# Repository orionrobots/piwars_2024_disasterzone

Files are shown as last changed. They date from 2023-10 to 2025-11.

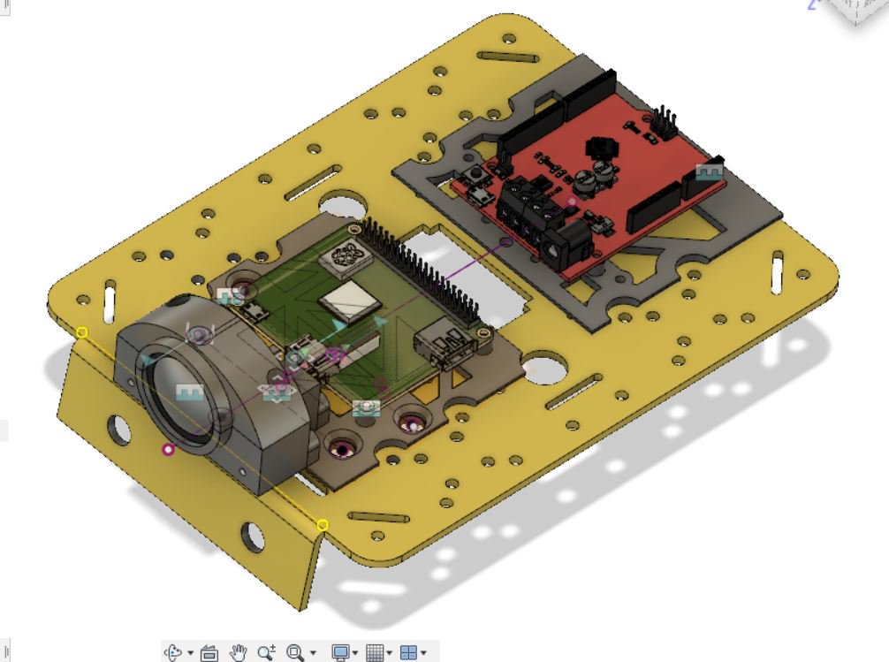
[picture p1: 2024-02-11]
hardware/pictures_for_blog/Dx8H_vfXQAc5lHb.jpg

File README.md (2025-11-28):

# piwars_2024_disasterzone

Code for Piwars 2024 robot

## 📋 Validation Infrastructure

See **[VALIDATION_ROADMAP.md](VALIDATION_ROADMAP.md)** for the plan to add offline validation (CI, testing, simulation).

## road map for motor board

Let's make the interface the same as the [GPIOzero Robot](https://gpiozero.readthedocs.io/en/stable/api_boards.html#robot). We can support this for multiple motor boards, and it will make it easier to swap them out.

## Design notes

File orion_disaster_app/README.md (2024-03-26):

# Orion disaster robot control app

This is an app designed to interact with the robot from a device.

It uses expo/react native.

## Installation

- Ensure you have up-to-date node.
- Install with `npm install`.
- Run with `npm run go`.
- Install the expo go app on your android/ios device.
- Scan the QR code with the camera, which shoudl launch the app.

You will need to close the app and re-open it with the QR code when you stop/start the
server.

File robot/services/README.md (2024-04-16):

# Services

These are robot mqtt services.

Each should have the following:

- notes.md -> Notes on the device/board/algorithm.
- service.py -> Main service code.
- install.py -> PyInfra code to install the service and dependencies.
    - Should include installing a systemd unit file, and restarting if necessary.
- service.j2 -> template for the service systemd file.

## Sending a message to a service

To send a message to a service, publish to the topic:

```bash
source /etc/robot.env
mosquitto_pub -t "motors/forward" -m '{"speed": 1}' -u $MQTT_USERNAME -P $MQTT_PASSWORD
```

Robot.env is deployed from your .env, and will contain the needed secrets for mqtt access.

## Tips

Vacuum logs - `journalctl --vacuum-time=2d` - keep only 2 days. These MQTT services can generate a lot of logs!

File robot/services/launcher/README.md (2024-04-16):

# Launcher service

An MQTT service to launch/stop other services.
Can also power down the Raspberry Pi.

## Messages and topics

- launcher/start 'service_name' : Start the service 'service_name'
- launcher/stop 'service_name' : Stop the service 'service_name'
- launcher/poweroff : Power off the Raspberry Pi

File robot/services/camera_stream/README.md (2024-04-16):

# Camera commands we can use (pre-python)

- https://www.tomshardware.com/how-to/use-raspberry-pi-camera-with-bullseye
- https://www.raspberrypi.com/documentation/computers/camera_software.html - This is bookworm, so newer than the bullseye installed here.

## Getting a still

```bash
libcamera-still --datetime -e png --rotation 180
ls *.png
```

Retrieve it:

`
rsync danny@big-ole-yellow.local:0415195843.png .
`

You can now view locally

## Streaming

```bash
libcamera-vid --rotation 180 --listen -o

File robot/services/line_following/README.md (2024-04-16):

## Line Following Control
- line_following/startstop - empty payload to start/stop the line following service.
- all/stop - empty payload to stop all services.
- listening to line_follower/differences for line sensor readings.

## Line Following Output
- line_follower/control
- motors/left, motors/right

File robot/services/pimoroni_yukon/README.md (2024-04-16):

# Pimoroni Yukon robot service

Slot usage plans:
- Slots 2 and 4 are motors + encoders
- 4 is an LED Strip
- 5 Servo motors

| Other services | --> | MQTT Broker (Mosquitto) | --> | Yukon Service (Runing on the Pi) | --> Serial port ==> | Yukon |

## Links and docs

- https://github.com/pimoroni/yukon/blob/main/docs/reference.md#pimoroni_yukon-reference
- https://pythonhosted.org/pyserial/examples.html#tcp-ip-serial-bridge
- https://forum.micropython.org/viewtopic.php?t=11336
- https://shop.pimoroni.com/products/yukon?variant=41185258111059
- https://shop.pimoroni.com/products/big-motor-encoder-module-for-yukon?variant=41186939437139
- https://pypi.org/project/mpremote/

## Communication

Currently, the firmware on the Yukon is Micropython based. Over USB that only offers a single REPL/Serial.
We will do the follwoing:
- Use MPRemote to start/stop/deploy code.
- When it is running, use the repl to send commands to this part of the robot.

The communication protocol can be nice and simple. Since we are working with MQTT, we can translate to serial:
- The service subscribes to topics.
- Any topic it's subscribed to is passed on to the robot - topic/name:payload
- An end of payload is denoted by what? Its a line for now. topic/name:payload\n.
- Any serial responses are published to the topic: topic/name:payload

The commands for the motor will be the same as other motor services here.

## Mounting and reflashing the firmware on the RP2040 on Yukon

From time to time, a micropython firmware update may be needed. This is how you do it:

- Download the latest firmware for Yukon.
- Stop the yukon service with: `sudo systemctl stop yukon`
- Power off the yukon.
- Hold the boot/user button and power it on.
- `sudo mkdir -p /mnt/pico`
- `sudo mount  sudo mount /dev/sda1 /mnt/pico`
- `sudo cp <firmware> /mnt/pico`
- `sudo sync`
- `sudo umount /mnt/pico`
- You should probably run the installer here again.

Refer to section 3.2.1 in https://datasheets.raspberrypi.com/pico/getting-started-with-pico.pdf.

## Updating the Pimoroni yukon libraries

- Stop the yukon service with: `sudo systemctl stop yukon`
- Download the libaries, unzip them.
- cd into the directory.
- mpremote cp lib :
- You probably want to run the install/restart the service now

## Sunfounder Line Follower Module

- https://github.com/sunfounder/SunFounder_Line_Follower
```python
>>> from machine import Pin, I2C
>>> i2c = I2C(0)
>>> i2c.scan()
[17, 32, 38]
>>> [int (n) for n in i2c.readfrom(0x11, 10)]
[0, 12, 0, 33, 0, 17, 0, 16, 0, 9]
>>> [int (n) for n in i2c.readfrom(0x11, 10)]
[0, 182, 0, 169, 0, 162, 0, 219, 0, 175]
>>> i2c.readfrom(0x11, 10)
b'\x00\x0e\x00!\x00\x11\x00\x12\x00\t'
>>> struct.unpack(">HHHHH",  i2c.readfrom(0x11, 10))
(13, 13, 15, 16, 7)
>>> struct.unpack(">HHHHH",  i2c.readfrom(0x11, 10))
(11, 123, 389, 406, 327)
```
Device address is 0x11. 0x32 and 0x38 are IO extenders on the Yukon.

## Line Following Module MQTT Protocol
- Control messages topics are 'line_follower/control {"enabled": true}' and 'line_follower/control {"enabled": false}'.
- The line sensor readings are published to 'line_follower/differences' as a JSON object: [0, 0, 0, 0]

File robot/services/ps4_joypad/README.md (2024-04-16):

# Playstation 4 JoyPad service

This service allows you to control the robot using a PS4 controller. The intention is to patch the Joystick to emit events to the MQTT bus to control other services.

## Decision

One decision is if the Joypad would emit generic events, like joystick moved, and button press events, or to make it a direct control surface, like the phone app, and emit motors move and similar events directly.

For now, this service will emit direct motor and servo control events.

## Installation

This is a pyinfra based installation. The installation will need the following:

- A PS4 controller.
- You will need to pair and trust this with the Pi. This is a one time operation.
    - Using the command Bluetoothctl from ssh:
```bluetoothctl
discoverable on
pairable on
agent on
default-agent
scan on
```
Wait for the controller to appear, then:
```bluetoothctl
pair <controller mac>
trust <controller mac>
```
- Note the MAC for future use, this will become part of the environment for the Pi.
- The installer will install required packages and the service.

## Service intention

- The service will be started at boot, but will not try to connect the joypad, or issue commands until a Yukon/button a press occurs. At this point, it will do a bluetoothctl connect command, wait a short time, and seek the controller device.
- It will then havea  main loop issuing commands on stick events.

## Mappings

The mappings are as follows:
- Left analog stick: control the wheels/tracks
- Right analog stick: control servo 0,1 - pan and tilt on the nerf turret
- Left trigger held: Arm the rollers. When it's released, the rollers will stop.
- Right trigger: Fire the nerf dart
- Triangle: Stop all motors

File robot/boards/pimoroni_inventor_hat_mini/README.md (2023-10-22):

# Notes on Pimoroni inventor hat mini

Code:
- https://github.com/pimoroni/inventorhatmini-python/blob/main/inventorhatmini/__init__.py
- https://github.com/pimoroni/inventorhatmini-python/tree/main

This hat can do more - it has on board lights and audio output.

- https://shop.pimoroni.com/products/inventor-hat-mini?variant=40588023464019
- https://pinout.xyz/pinout/inventor_hat_mini

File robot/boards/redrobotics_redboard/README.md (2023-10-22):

# Notes on RedRobotics Redboard+

This is for driving a robot using the [RedRobotics Redboard+](https://github.com/RedRobotics/RedBoard). This board deals with nearly everything a Raspberry Pi robot will need.

Like the other motor modules in this project, it will follow the GPIOZero robot interface.  

## Setup

The repo describes setup as `curl -L https://raw.githubusercontent.com/RedRobotics/RedBoard/master/system/setup.sh | bash`.

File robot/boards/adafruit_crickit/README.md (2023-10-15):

# Notes on Adafruit Crickit

https://learn.adafruit.com/adafruit-crickit-hat-for-raspberry-pi-linux-computers
Download seesaw firmware:
https://github.com/adafruit/seesaw/releases/tag/1.1.6

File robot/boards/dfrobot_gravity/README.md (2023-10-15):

# Notes on Gravity Expansion Hat

This is for driving a robot using the [DFRobot Gravity Expansion hat](https://thepihut.com/products/gravity-io-expansion-hat-for-raspberry-pi-4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), plus an external motor driver board connected to it's pins.

Like the other motor modules in this project, it will follow the GPIOZero robot interface.  

- [Product wiki](https://wiki.dfrobot.com/IO%20Expansion%20HAT%20for%20Raspberry%20Pi%20%20SKU%3A%20%20DFR0566)
- [Expansion hat](https://thepihut.com/products/gravity-io-expansion-hat-for-raspberry-pi-4)
- [Motor driver](https://thepihut.com/products/gravity-2x-1-2a-dc-motor-driver-tb6612fng) - This is just a TB6612fng with headers

## Setup

The wiring is as follows, using the gravity modular wires:

| Motor Driver | Gravity Hat | Raspberry Pi |
| --- | --- | --- |
| PWM1 | PWM0 | I2C |
| DIR1 | D0 | GPIO 0 |
| PWM2 | PWM1 | I2C |
| DIR2 | D1 | GPIO 1 |

This allows the motor board to use only 2 PWM outputs, freeing up a further 2 for use with servo motors.

## Usage

We should be able to see the board on I2C when we power up the Pi.

For example: `fab -e -H danny@learnrob3.local show-i2c-devices`

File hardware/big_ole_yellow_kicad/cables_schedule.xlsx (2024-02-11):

Cables for robot |  | Type | Length
Pi I2c | Arduino I2c | 3 pin XH
3xXH | 3xXH
GND | GND
SCL | SCL
SDA | SDA
Pi I2C | Line Sensor | 4 pin XH
5V | scl
SDA | sda
SCL | 5v
GND | GND
Pi | HC SR04 | 4 pin XH to 4 Pin dupont
3v | 3v | 3x
sig | sig
sig | sig
gnd | gnd
Arduino | WS2801 | 4 pin XH
5v | 5v
sig | sig
sig | sig
gnd | gnd

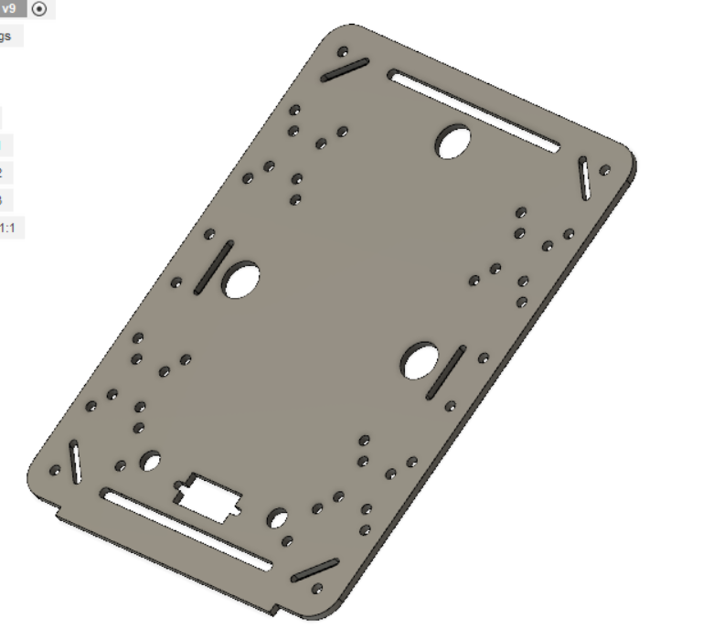
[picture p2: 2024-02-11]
hardware/pictures_for_blog/chassis_plate.PNG

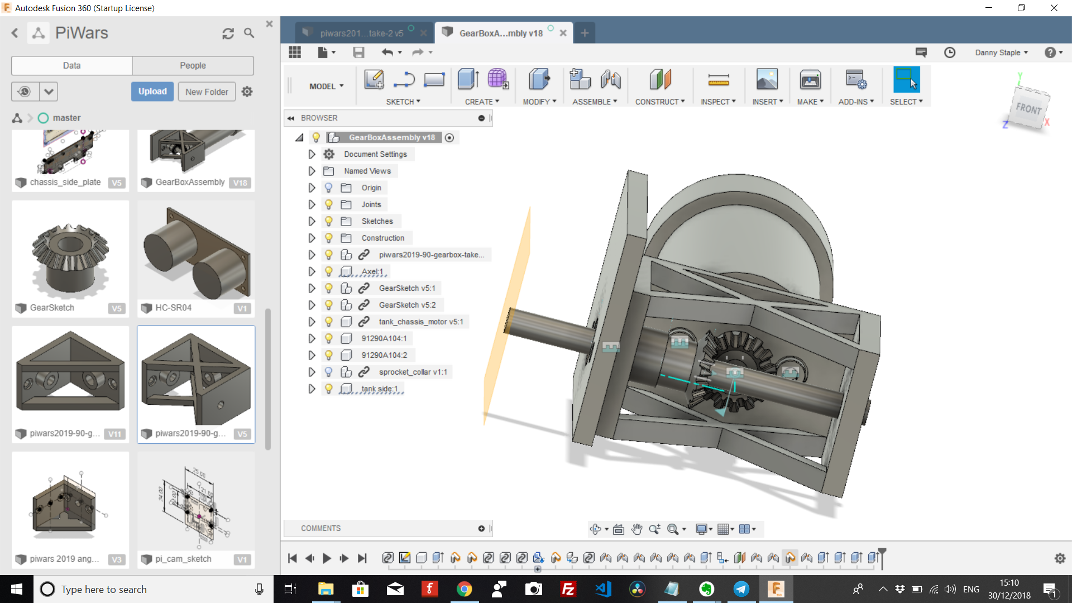
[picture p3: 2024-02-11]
hardware/pictures_for_blog/Screenshot 2018-12-30 15.10.52.png

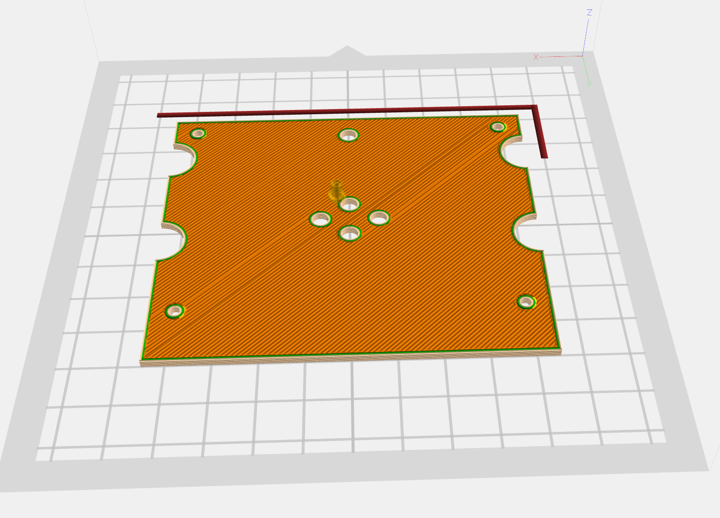
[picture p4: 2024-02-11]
hardware/pictures_for_blog/Screenshot 2023-12-10 at 17.55.50.png

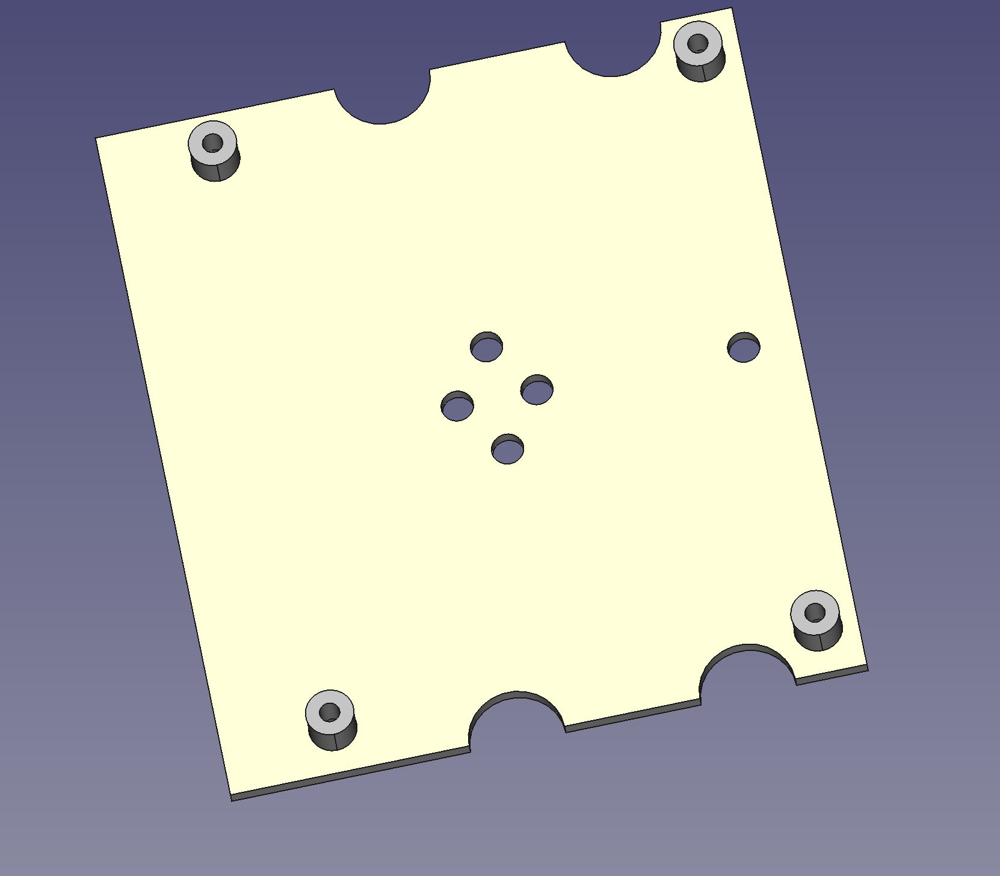
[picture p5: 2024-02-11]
hardware/pictures_for_blog/Screenshot 2023-12-10 at 17.55.58.png

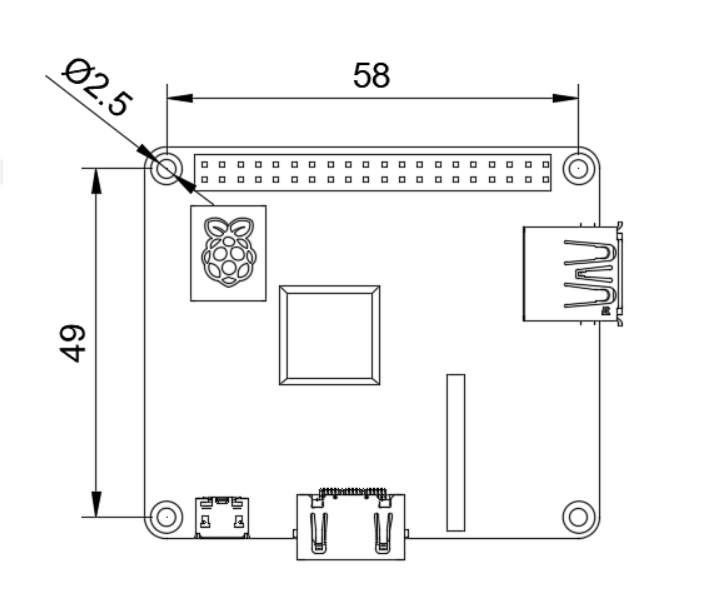
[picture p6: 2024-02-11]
hardware/pictures_for_blog/pi_drawing.png

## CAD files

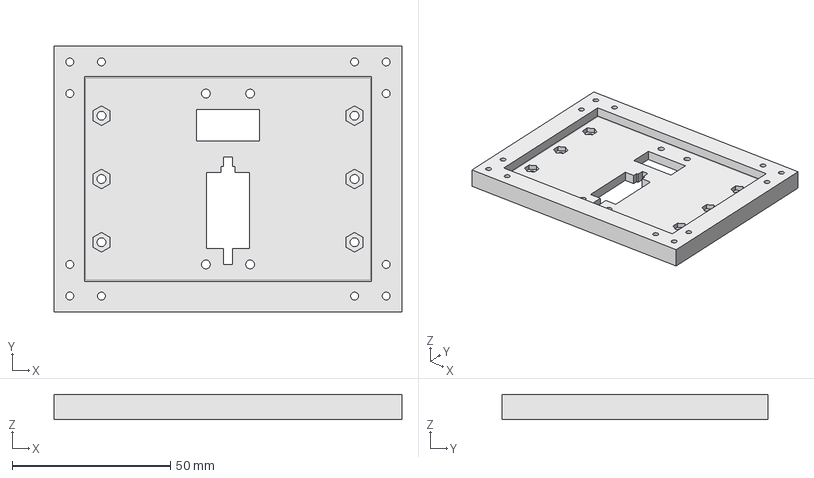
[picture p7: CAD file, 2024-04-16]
hardware/freecad_designs/attachment_mounting_plate.FCStd
110.0 x 84.0 x 8.00 mm

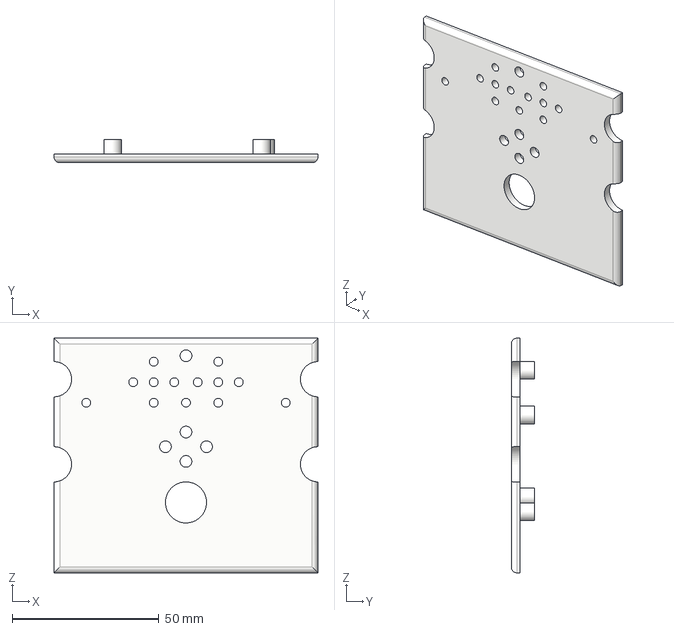
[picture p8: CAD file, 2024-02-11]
hardware/freecad_designs/imported/4DuinoPlate.step
90.0 x 8.00 x 80.0 mm

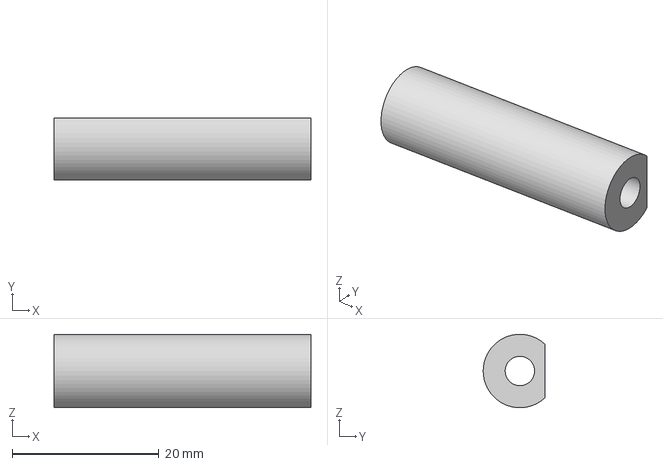
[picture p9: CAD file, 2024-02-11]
hardware/freecad_designs/imported/sprocket_collar v1.step
35.0 x 8.40 x 10.00 mm

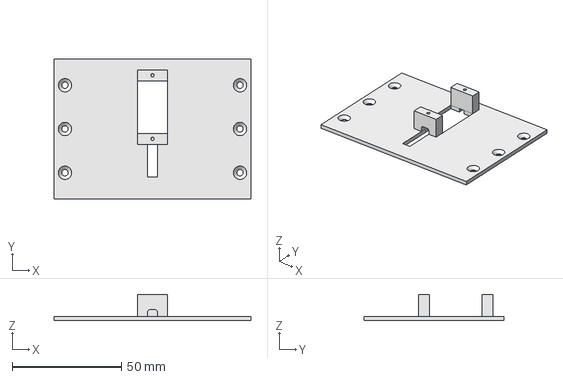
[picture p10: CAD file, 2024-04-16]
hardware/freecad_designs/NerfPlate.FCStd
90.0 x 64.0 x 12.0 mm

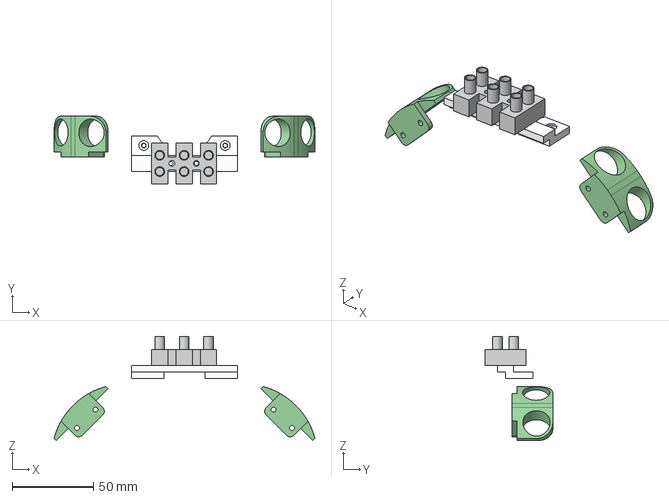
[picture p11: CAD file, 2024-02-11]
hardware/freecad_designs/imported/FrontSensorClip (1).step
160.3 x 41.5 x 64.1 mm

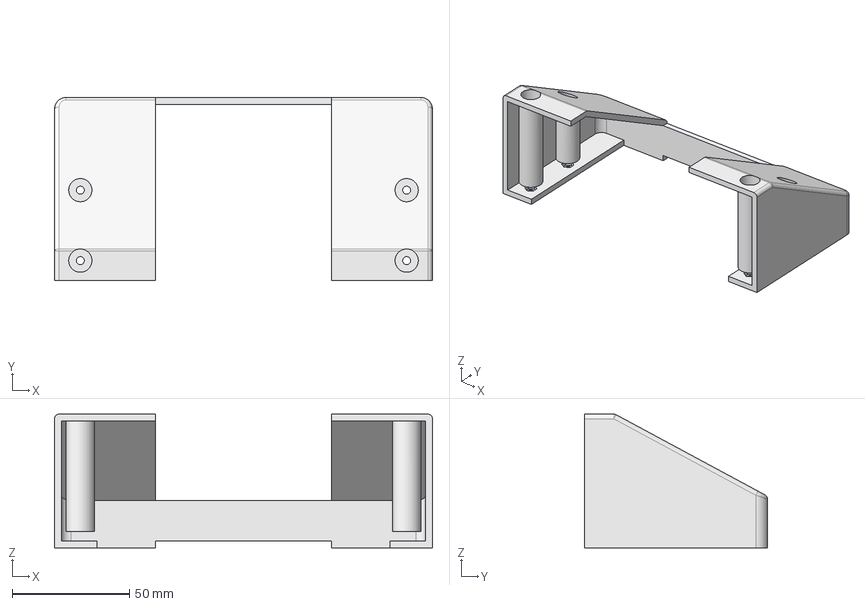
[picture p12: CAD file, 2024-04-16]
hardware/freecad_designs/rearhull2.FCStd
161.0 x 78.0 x 57.0 mm

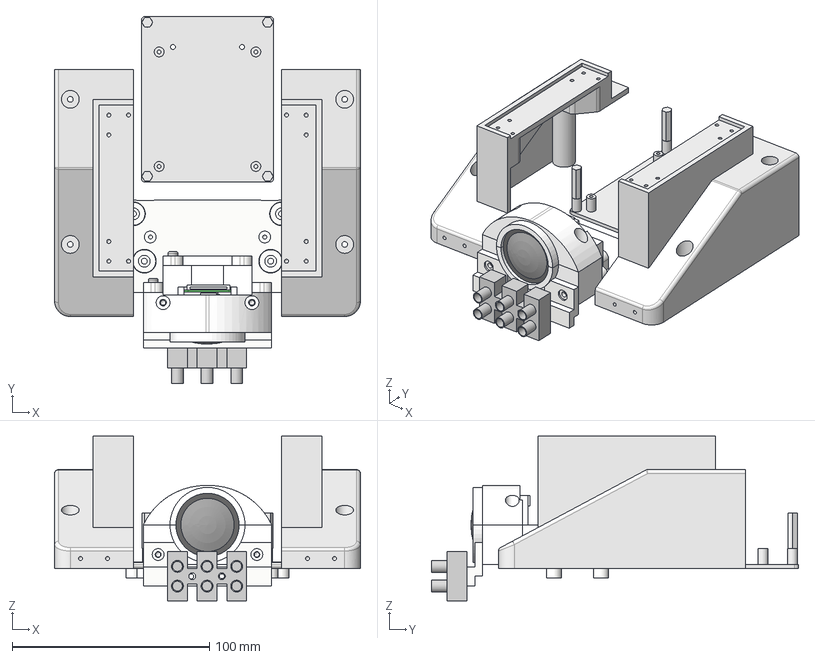
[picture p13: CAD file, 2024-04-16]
hardware/freecad_designs/BigOleYellow.FCStd
155.0 x 186.0 x 83.5 mm
YukonPiMount
M25StandOff x 4
RearLeftPeg
FrontLeftPeg
FrontRightPeg
RearRightPeg
CameraMountCover x 2
CameraMountBase x 2
PCB001
Zif Connector001
Camera Lense001
Camera PCB connector001
OuterBoltL
OuterBoltR
FrontLens x 2
LensRim x 2
PinoonChopBloc v005
PiNoonClip
Hull2_Body
Hull2_Body (Mirror #4)

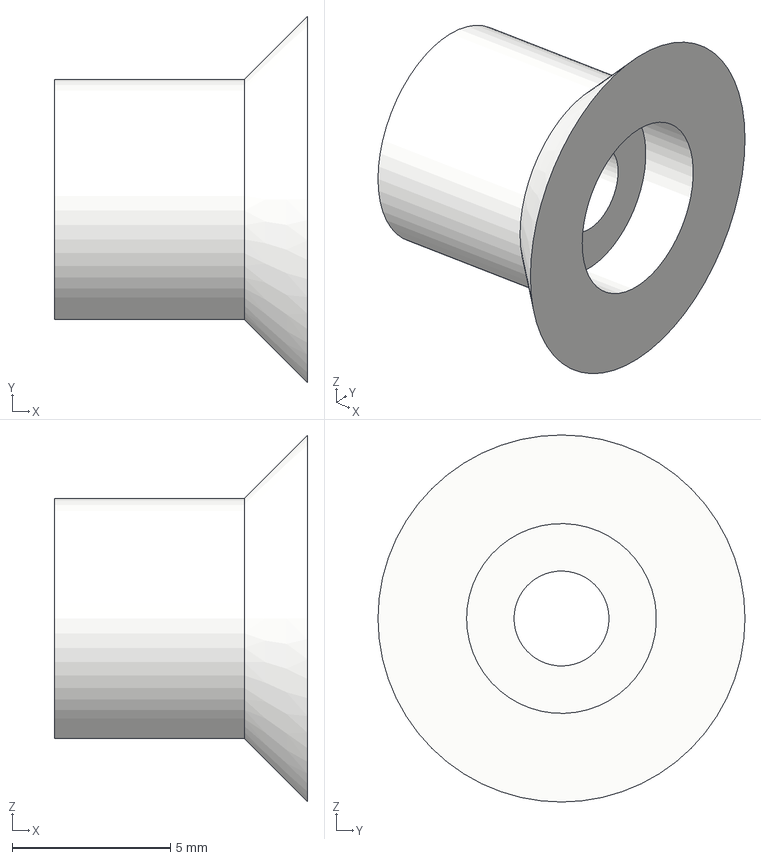
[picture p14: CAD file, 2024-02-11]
hardware/freecad_designs/imported/Peg.step
8.00 x 11.6 x 11.6 mm

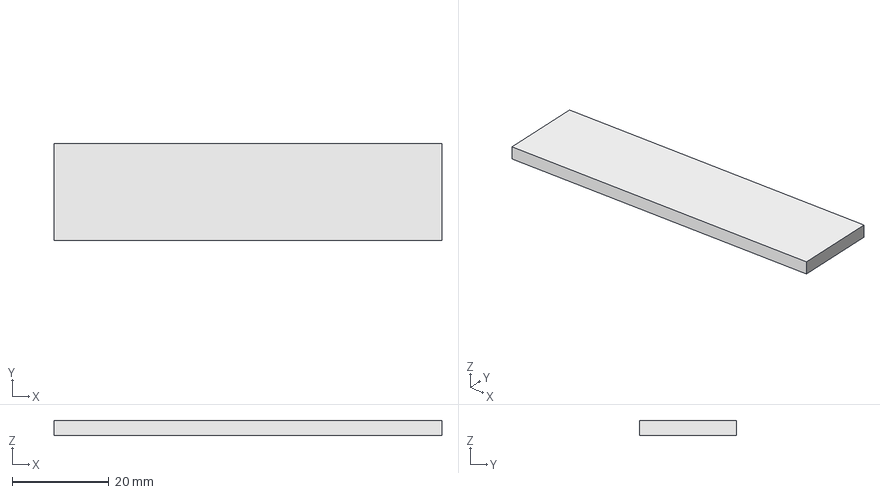
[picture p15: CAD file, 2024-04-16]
hardware/freecad_designs/Grabber.FCStd
80.0 x 20.0 x 3.00 mm

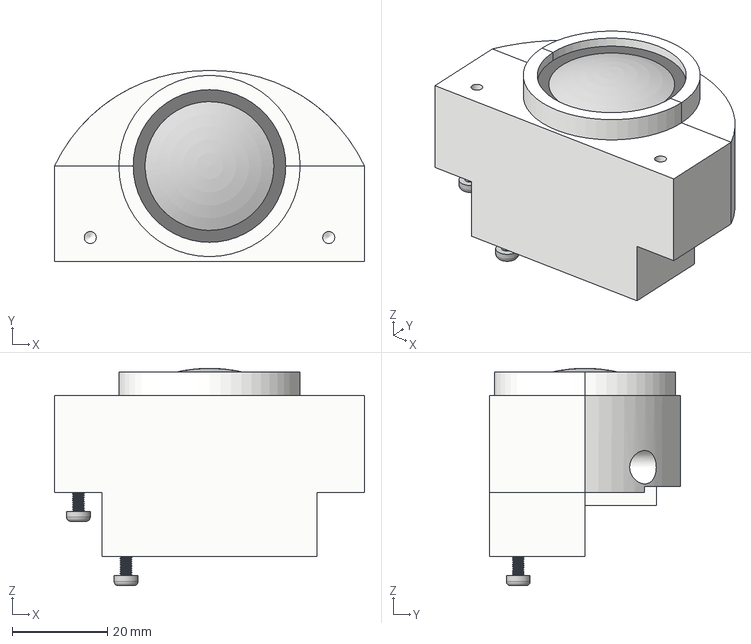
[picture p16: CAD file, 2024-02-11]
hardware/freecad_designs/imported/StaticSensorMount.step
65.0 x 40.0 x 45.6 mm
WideAngleLens
92492A657 x 2

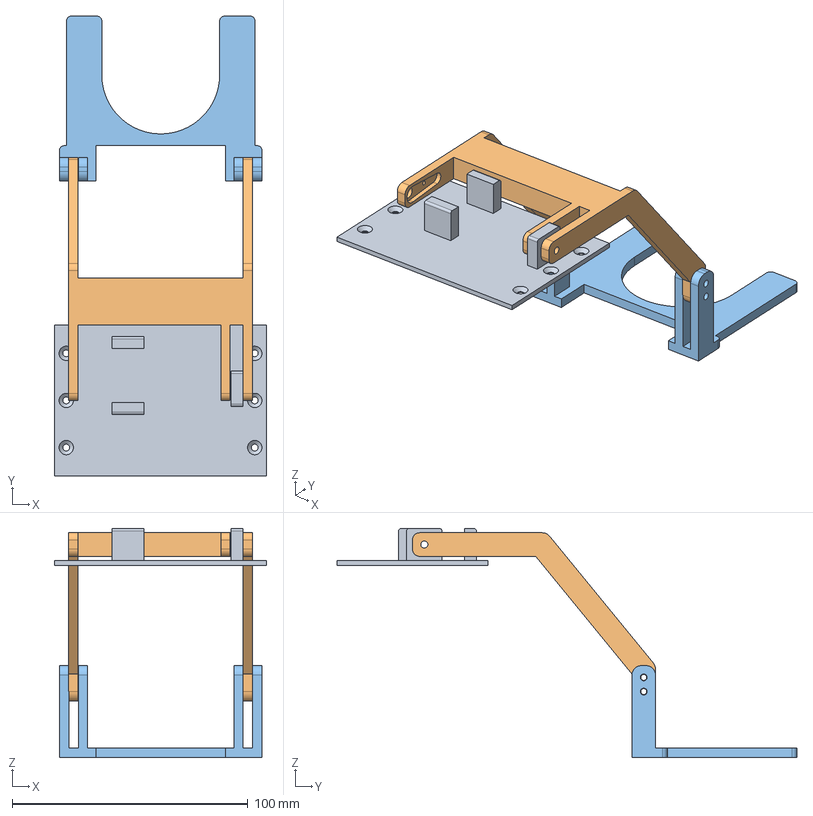
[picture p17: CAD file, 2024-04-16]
hardware/freecad_designs/GrabAndLift.FCStd
90.0 x 195.1 x 97.2 mm
GrabAndLiftBase
GrabAndLiftArm
GrabberFrame

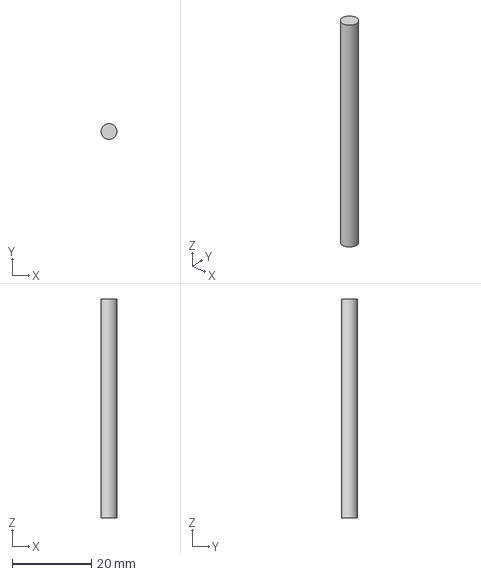
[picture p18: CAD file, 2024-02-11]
hardware/freecad_designs/imported/Axel.step
4.00 x 4.00 x 55.4 mm

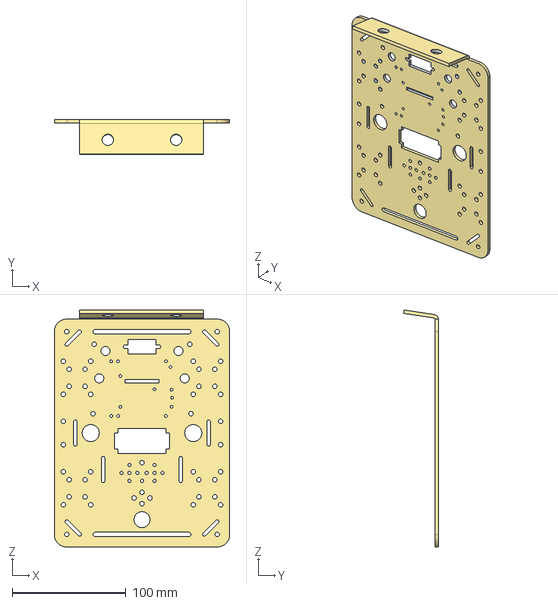
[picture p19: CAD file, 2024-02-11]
hardware/freecad_designs/imported/ChassisBody v26.step
154.0 x 30.4 x 208.0 mm

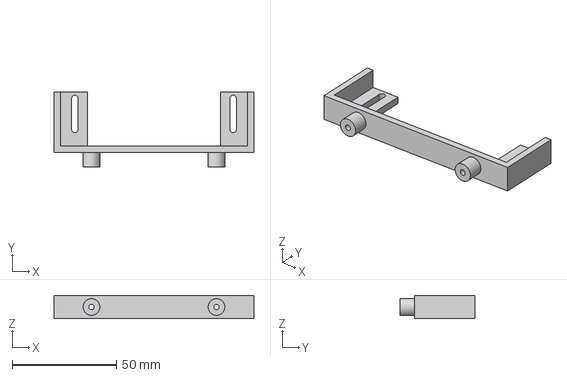
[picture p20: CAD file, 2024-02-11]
hardware/freecad_designs/imported/LineSensorSlider.step
96.0 x 36.0 x 11.2 mm

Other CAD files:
hardware/freecad_designs/YukonBoard.FCStd
hardware/freecad_designs/BigOleYellowChassisPlate.FCStd
hardware/freecad_designs/imported/tank_chassis_motor v6.step
hardware/freecad_designs/imported/pimoroni-super-wide-angle-lens v3.step
hardware/freecad_designs/3d_printable_servo_piston.FCStd
hardware/freecad_designs/BatteryClipParts.FCStd
hardware/freecad_designs/CameraMount.FCStd
hardware/freecad_designs/FrontSensorParts.FCStd
hardware/freecad_designs/RaspberryPi3a+.FCStd
hardware/freecad_designs/UltrasonicSensorMount.FCStd
hardware/freecad_designs/chassis-plate-imported.FCStd
hardware/freecad_designs/gearbox.FCStd
hardware/freecad_designs/imported/Anker_usb_battery v1.step
hardware/freecad_designs/imported/GearSketch v6.step
hardware/freecad_designs/imported/Lower Plate.step
hardware/freecad_designs/imported/PiPlate v3.step
hardware/freecad_designs/imported/PinoonChopBloc v3.step
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

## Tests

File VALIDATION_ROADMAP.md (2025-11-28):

# Validation Roadmap for PiWars 2024 Disaster Zone

A phased approach to implementing offline validation, reducing dependency on physical robot testing.

## Current State

- **Build System**: Poetry (Python), npm (React Native)
- **Pre-commit Hooks**: Basic checks configured
- **Testing**: Manual scripts only, no automated framework
- **CI/CD**: None

## Validation Strategies

### 1. Build & Compile Checks

**Python**:
- GitHub Actions workflow with Poetry
- Verify all Python files compile
- Test on Python 3.12

**React Native** (Android only):
- `npm ci` to install dependencies
- Build validation for Android target

**Triggers**: Every push, every PR  
**Gating**: Yes - block merge on failure

### 2. Linting

Use **MegaLinter** for comprehensive multi-language linting:
- Python (Ruff already configured)
- JavaScript/JSX (ESLint)
- Markdown, YAML, JSON validation
- Dockerfile linting
- Shell script checking

**Triggers**: Every push, every PR  
**Gating**: Gradual - informational initially, then enforced

### 3. Unit Testing

**Python** (pytest):
- Test pure logic modules: PID control, settings, service base
- Mock hardware dependencies (GPIO, I2C, SPI)
- Coverage reporting with pytest-cov

**React Native** (Jest):
- Test component logic
- Test utility functions
- Mock native modules

**Target**: < 2 minutes execution  
**Triggers**: Every push, every PR  
**Gating**: Yes

### 4. Integration Testing

- Test MQTT service communication with test broker
- Mock board driver interfaces
- End-to-end service stack tests (without hardware)

**Target**: < 5 minutes execution  
**Triggers**: Every push, every PR  
**Gating**: Yes (with mocked hardware)

### 5. Dry Running

- Add `--dry-run` flag to services
- Log actions instead of executing
- Validate command sequences without hardware

**Triggers**: PRs affecting robot control logic  
**Gating**: Yes

### 6. Simulation

- Lightweight 2D Python-based simulator
- Basic physics, sensors, arena representation
- Headless mode for CI
- MQTT integration with real services

**Triggers**: Major changes, releases  
**Gating**: Informational initially

## Trigger Matrix

| Change Type | Build | Lint | Unit | Integration | Dry Run | Simulation |
|---|---|---|---|---|---|---|
| Python code | ✓ | ✓ | ✓ | ✓ | If control | If control |
| React Native | ✓ | ✓ | ✓ | - | - | - |
| Config files | ✓ | ✓ | - | - | - | - |
| Documentation | - | ✓ | - | - | - | - |
| Tests | ✓ | ✓ | ✓ | ✓ | - | - |
| Deployment | ✓ | ✓ | - | - | ✓ | - |

## Gating Strategy

**Phase 1**: Gate on build failures only; linting and tests informational  
**Phase 2**: Gate on build, critical lint errors, test failures  
**Phase 3**: Gate on all checks except simulation; require minimum coverage

## Implementation Order

### Phase 1: Foundation
1. GitHub Actions workflow for Python builds
2. MegaLinter integration
3. pytest setup with initial unit tests
4. React Native build validation (Android)

### Phase 2: Core Testing
1. Expand unit tests (Python and React Native)
2. Hardware mocking framework
3. Integration tests with MQTT
4. Coverage reporting

### Phase 3: Advanced
1. Dry-run implementation
2. Simulation architecture design
3. Basic 2D simulator
4. Dry-run in CI

### Phase 4: Refinement
1. Simulation in CI
2. Enhanced coverage
3. Documentation
4. Team training

## GitHub Issues Structure

### Epic 1: CI/CD Foundation
- Set up GitHub Actions for Python builds (Python 3.12)
- Add React Native Android build validation
- Create PR status check requirements
- Document CI setup

### Epic 2: Linting
- Set up MegaLinter
- Configure baseline for existing violations
- Create linting documentation

### Epic 3: Unit Testing
- Configure pytest
- Write tests for PID control, settings, service base
- Create hardware mocking framework
- Add coverage reporting
- Configure Jest for React Native
- Write React Native unit tests

### Epic 4: Integration Testing
- Set up test MQTT broker
- Write service integration tests
- Mock board driver interfaces
- Create end-to-end test scenarios

### Epic 5: Dry Run
- Design dry-run architecture
- Implement dry-run flag in base classes
- Add dry-run to motor and sensor services
- Create test scenarios
- Integrate in CI

### Epic 6: Simulation
- Research and select approach
- Implement basic 2D simulator
- Create simulated sensors and arena
- Headless mode for CI
- Write simulation test scenarios

### Epic 7: Documentation
- Testing guide for contributors
- CI/CD pipeline documentation
- Troubleshooting guide

## Risks and Mitigations

| Risk | Mitigation |
|---|---|
| Hardware dependencies | Comprehensive mocking, dry-run mode |
| Simulator complexity | Start simple 2D, iterate based on needs |
| Test maintenance | Keep tests focused, good documentation |
| CI too slow | Parallel execution, caching, separate fast/slow tests |

## Success Criteria

- 100% PRs validated by CI
- 70%+ code coverage
- < 5% PRs require hardware testing
- CI completes in < 10 minutes

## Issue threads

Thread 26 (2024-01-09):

Put the hardware design files into this repository

dannystaple, 2024-01-09:
Currently the hardware design files are somewhere on my hard drive.
Ensure that the Big Ole Yellow hardware design files are in git.
- 3D CAD Files
- Hardware notes
- KiCAD/Fritzing files.
- Inkscape design files where they are not in other CAD.
- For now a directory of the archived old stuff, which we can later remove so it's kept in git history.
- Image files like photos/screenshots should NOT be here, and probably be in appropriate Orionrobots blog post folder.

## Definition of done
- [ ] PR(s) merged with hardware design/build files and notes
- [ ] None of this is sat on my HD and not in Git

Closed 2024-02-11.

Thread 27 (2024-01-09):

Create the universal attachment plate shell

dannystaple, 2024-01-09:
Finish the plate for adding attachments, including the shell to support it.
This should be somewhere above the Raspberry Pi, have points to bolt in attachments like the nerf gun or lifter, and a recess for an SG/MG90 servo motor, along with cabling ports and bolt locations.

Access to the yukon wiring shouldn't be obstructed by this shell segment.

## Definition of ready

- #26
- #58

## Definition of done

- [x] Mounting plate and upper shell design added into FreeCAD
- [x] 3D printed shell with the design bolted onto the robot ready for use
- [x] PR merged with the files

Closed 2024-04-16.

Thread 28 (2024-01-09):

Adapt the nerf launcher

dannystaple, 2024-01-09:
Adapt the nerf launcher with a base design that fits the universal mounting plate #27 .
The nerf launcher should be able to bolt right into the shell mounting plate, with the mounting screws accessible under the launcher, and the servo motor recessed into its pocket.

It should be relatively quick to install and remove the turret.

The motor control cables should then be connected to the Yukon, along with the power control for the motors (big power with flyback protection module needed for this).

Simple test code is all that's needed, not the full endpoint code just yet.

## Definition of ready

- [x] Roller electronics design
- [x] Code design to start/stop rollers
- #29
- #27

## Definition of done
- [x] FreeCAD design for the nerf turret base added (we don't need the whole launcher, only the base)
- [x] Turret base 3D printed and attachment tested in on the real robot
- [x] Simple Yukon test code for flexing the turret tried (Danny may have this code already) checked in
- [x] PR merged with all of the above

Closed 2024-04-16.

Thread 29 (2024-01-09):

Extend Yukon service to activate and control servo motors

dannystaple, 2024-01-09:
Extend the Yukon service #25 to support up to 4 servo motors. These will be attached to one slot of the Yukon, determined in the service for now.

Topics:
- /servomotors/position: index, angle -> move the servo motor to the intended angle in degrees
- /servomotors/detach: [index] -> Detach servo motors (stop driving them). All if no index is provided.

Behaviour:
- Detach all servo motors in the stop method, if there's no contact for a second.

A simple phone app screen could be set up to test servo motors with angle + number sliders, and detach buttons. The back button will send detach all.

## Definition of ready

- #25 Yukon service
- #35

## Definition of done

- [x] Yukon topics created
- [x] Phone app screen created
- [x] Tested with a few loose servo motors
- [x] PR merged supporting servo motors

Closed 2024-04-16.

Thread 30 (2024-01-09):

Grab and lift mechanism

dannystaple, 2024-01-09:
Build the grab and lift mechanism. It should fit the #27 attachment plate. It won't be using the servo recess, but make be bolted with good physical rigid attachment to the plate.

It should have up to 2 servo motors, for grippers to close around a barrel (for eco-disaster) and to lift it a little.

Testing should show we can close the grippers around an object, and lift it without it sliding out.
The camera should be able to see over/under the mechanism - so lowered or raised it does not obscure the Camera.

## Definition of ready

- #29 Servo motor controls
- #27 Attachment shell

### Definition of done

- [x] FreeCAD design for grab and lift design
- [x] Mechanism 3D printed, assembled.
- [x] Mechanism tested by bolting onto the mounting plate.
- [x] PR merged with tested mechanism design

Closed 2024-04-16.

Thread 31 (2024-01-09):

PyInfra Yukon Code deployment

dannystaple, 2024-01-09:
Make a simple test, pre-empting the Yukon service to deploy code to it.
This route will be desktop-via pyinfra->Raspberry PI-via mpremote->Yukon.

Pyinfra will drive MPRemote to deploy code to the Yukon.

## Definition of Ready

- Blocked by #24

## Definition of done

- [x] Demonstration code written, perhaps to flash LEDs
- [x] Demonstration code pushed via pyinfra->mpremote path
- [x] Demonstration code shown running
- [x] Change to Demo code, and running deploy again shows the changes
- [x] PR merged

dannystaple, 2024-01-09:
Removing #32  - we can do this with the NiMH AA's for now.

dannystaple, 2024-01-09:
Note - I couldn't see an mpremote apt package, so pip install will work. User is probably good enough.

dannystaple, 2024-01-09:
Mpremote is installed, but the Pi cannot find the Yukon when plugged in via USB.

```bash
danny@big-ole-yellow:~ $ mpremote devs
/dev/ttyAMA0 None 0000:0000 None None
```

I've verified I can reach it with MP remote from the MAC using a USB C->C cable. However, from the Pi 3A it must be a USB A->C cable.

Lsusb to list usb devices:

```bash
danny@big-ole-yellow:~ $ lsusb
Bus 001 Device 001: ID 1d6b:0002 Linux Foundation 2.0 root hub
```

Hypotheses:
- The cable is problematic. I have a few cables that don't work, I probably need my tester to be sure.
- Some permissions are preventing me seeing the devices. I could see if lsusb as root will do it, or make a root virtualenv, temporarily install mpremote and try that.
- The USB port on the 3A is not compatible with a Pico
- There's not enough power to the Yukon to work (the connecting it to the Mac test about dismisses this, but using bench power to test is a good idea here.

dannystaple, 2024-01-10:
Grabbed a standard Pico on a USB-micro, and checked that `mpremote ls` works from my laptop. I've plugged into the Raspberry Pi, and this works first time. I am highly suspecting that none of those USB-A->C cables are good.

dannystaple, 2024-01-10:
Made that work with the yukon with a known good USB micro cable and USB micro to C adaptor. Rubbish cables. A new tester is on the way for that.

dannystaple, 2024-01-10:
With debug, looks like this:
```bash
--> Beginning operation run...
--> Starting operation: Install mpremote
    [pyinfra.api.operations] Starting operation {'Install mpremote'} on big-ole-yellow.local
    [big-ole-yellow.local] No changes

--> Starting operation: Copy test file
    [pyinfra.api.operations] Starting operation {'Copy test file'} on big-ole-yellow.local
    [pyinfra.connectors.ssh] Attempting upload of /Users/danielstaple/git_work/orionrobots/piwars_2024_disasterzone/robot/services/pimoroni_yukon/rp2040/test_flash_leds.py to mpremote/main.py
    [pyinfra.connectors.ssh] Running command on big-ole-yellow.local: (pty=None) sh -c '/home/danny/.local/bin/mpremote cp mpremote/main.py :main.py'
    [pyinfra.connectors.ssh] Waiting for exit status...
    [pyinfra.connectors.ssh] Command exit status: 0
    [big-ole-yellow.local] Success

--> Starting operation: Reset the Yukon
    [pyinfra.api.operations] Starting operation {'Reset the Yukon'} on big-ole-yellow.local
    [pyinfra.connectors.ssh] Running command on big-ole-yellow.local: (pty=None) sh -c '/home/danny/.local/bin/mpremote reset'
    [pyinfra.connectors.ssh] Waiting for exit status...
    [pyinfra.connectors.ssh] Command exit status: 0
    [big-ole-yellow.local] Success

--> Results:
    Groups: robots / inventory
    [big-ole-yellow.local]   Changed: 2   No change: 1   Errors: 0
```

I was able to do the full trip deploy, make changes, and deploy again.
There's an issue if the file has the same size (which results in no change), which can be addressed to complete this.

dannystaple, 2024-01-10:
We can get the no change condition to work right now, using sha1 digests of the files:
```bash
--> Beginning operation run...
--> Starting operation: Install mpremote
    [big-ole-yellow.local] No changes

--> Starting operation: Copy test file
    [big-ole-yellow.local] No changes

--> Results:
    Groups: inventory / robots
    [big-ole-yellow.local]   Changed: 0   No change: 2   Errors: 0
```

Closed 2024-01-10.

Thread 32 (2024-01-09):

Yukon power supply upgrade

dannystaple, 2024-01-09:
Currently there is a space for 6xNiMH AA batteries.
Replace this with a space for two 18650 cells.
Wire these to the XT30 connector for the Yukon.
This is an upgrade - as the AA cells, while far from ideal, will power things for now.

## Definition of ready

## Definition of done

- [x] 18650 battery box fits under robot where line follower is
- [x] 18650 battery box wired correctly to Yukon
- [x] Yukon power up test demonstrated
- [x] If CAD changes are required, CAD Files PR is merged.

dannystaple, 2024-02-11:
Made without CAD change (for now)

Closed 2024-02-11.

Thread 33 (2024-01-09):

Fit line follower

dannystaple, 2024-01-09:
The line follower is not currently attached to the robot.
This needs to be fit to the robot, with 3D printed parts adjusted to make it work.
It needs to be electrically connected either to the Raspberry Pi or the Yukon's Pico.
We need to ensure we can get data from it.

Warning - a last attempt at connecting the line sensor to Raspberry Pi i2c led to nothing detected. May need to be UART, or try Yukon I2c.

## Definition of Ready

- #32 - if we connect to the Yukon
- #31 - if we connect to the Yukon

## Definition of done

- [x] Line follower attached to robot
- [x] Demonstration code shows we can read the line sensor
- [x] PR with any demo code and FreeCAD parts merged

Closed 2024-04-16.

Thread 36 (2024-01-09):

Add line following behavior

dannystaple, 2024-01-09:
Create the line following behavior. Using a PID.
Connect with MQTT to get line data, make motor adjustments, and publish pid monitoring data.

## Definition of ready

- #34
- #35
- #25
- #59

## Definition of done

- [ ] Line following PID code on the robot - launchable via SSH
- [ ] Line following demonstrated on a test track
- [ ] PR merged with Line following code

Closed 2024-06-21.

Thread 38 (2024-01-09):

Add phone launcher poweroff button

dannystaple, 2024-01-09:
Add a poweroff button to the phone, so cause the Raspberry Pi and yukon to shut down.

## Definition of ready

- #37
- #25

## Definition of done

- [ ] Phone main menu has a power off button for the robot
- [ ] Button turns off Raspberry Pi power, and stops Yukon main power.
- [ ] PR merged with tested code

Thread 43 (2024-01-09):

Build an Eco Disaaster test area

dannystaple, 2024-01-09:
We don't currently have a test area for eco disaster.

Build one we can use in our lab for testing.

## Definition of done

- [ ] Eco disaster test area with correct size and colours
- [ ] Some barrels!

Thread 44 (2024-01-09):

Eco Disaster Manual App page

dannystaple, 2024-01-09:
For a manual version of this (before we make an automatic one) we need a version of the Manual Drive app, with controls to deal with the barrel grab and lift mechanism.

## Definition of ready

- #42
- #35
- #29
- #30

## Definition of done

- [ ] PR merged with a manual grab and lift page, with camera, joystick and servo motor controls
- [ ] Demonstrate we can lift a barrel and put it down without tipping it.

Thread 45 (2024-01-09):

Create Nerf Launcher control page - Zombie tower

dannystaple, 2024-01-09:
Create a nerf Launcher manual control page for manual tackling the Zombie tower.

This should have two joysticks, one for motors, and one for the nerf pan/tilt.
It should have a button to enable the rollers, and a button to fire.

It should use MQTT to talk to the Yukon service, to control the nerf turret.
The back button should stop rollers and detach all servo motors.

This will not use a camera view.

## Definition of ready

- #28
- #37

## Definition of done

- [x] Inkscape app screen mock up in Git with a rough design for the controls
- [x] PR merged with a page that can drive the robot, aim and fire the launcher mechanism

Closed 2024-04-16.

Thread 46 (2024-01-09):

Distance sensors service

dannystaple, 2024-01-09:
We need to electrically connect distance sensor (s), then have an MQTT service for their data.
For now build and implement for the simple HC-SR04 like sensor types.

## input

- /distancesensor_ctl/start -> start producing sensor data
- /distancesensor_ctl/stop -> stop producing sensor data

## output

- /sensors/distance:sensor_number, distance

## Definition of ready

- Plan for the distance sensor electrical connections

## Definition of done

- [ ] PR merged with Electronic CAD Files updated to show where sensors connect
- [ ] Distance sensors connected to the Raspberry Pi
- [ ] PR merged with simple test of sensors
- [ ] PR merged with distance sensor service and test of the service, deployed via PyInfra.

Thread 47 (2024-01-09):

Blind maze autonomous behaviour

dannystaple, 2024-01-09:
Create the blind maze autonomous behaviour.
We might need some thought on how distance sensors, and camera can combined to find the way out.

A monitoring app page with start, stop buttons. It can monitor MQTT sensor data, and debug MQTT messages from the behaviour.

## Definition of ready

- Planning on how to autonomously navigate
- Screen design for monitoring app page
- Build a blind maze style arena

## Definition of done

- [ ] PR merged with autonomous blind maze solver
- [ ] PR merged with phone app monitor page

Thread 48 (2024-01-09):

Zombie tower autonomous behaviour

dannystaple, 2024-01-09:
Utilise the camera and nerf launcher to aim at zombies with the nerf launcher, and fire a dart at them.
Create an app page with monitoring of the behavior, start and stop buttons.

We can potentially try using haar cascades, or some kind of image classifier, then figure out the launcher aim. We can initially treat the darts as shooting straight from the launcher muzzle.

## Definition of ready

- #42
- #45
- Test tower with printed test zombies to hit
- Design for how we'll do this

## Definition of done

- [ ] PR merged with autonomous launched darts at zombies
- [ ] PR merged for Page to monitor and start/stop the launcher behaviour

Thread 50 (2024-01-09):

Test ramp traction

dannystaple, 2024-01-09:
There's a concern about the traction of this robot, and if it will slide on a ramp.
Using manual drive, build ramps at a few different elevation angles using the foam board material (quite slippery), and see how the robot performs.

Determine courses of action to improve it, like insulation tape or rubberising the treads somehow

## Definition of ready

- #25

## Definition of done

- [ ] An assessment of what elevation the robot starts to slip instead of progressing up
- [ ] Changes made to improve this, or further tickets if they require bigger changes

Closed 2024-06-21.

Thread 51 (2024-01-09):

Raise the Yukon a CM or so for wire clearance

dannystaple, 2024-01-09:
Currently the wires for the Yukon to motors and wires for Raspberry pi power are bumping right into each other, and near impossible to work on.
Use standoffs to raise the Yukon, above the Pi, leaving some space under the yukon for getting wires into the Raspberry Pi.

## Definition of Done

- Space created under Yukon
- Raspberry Pi power USB cable easy to fit or remove

dannystaple, 2024-01-09:
Before
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

dannystaple, 2024-01-09:
After - using some long 2.5mm standoffs. Observed that the holes in the mounting plate are a little loose, and need to be smaller.

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

Closed 2024-01-09.

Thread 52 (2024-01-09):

Attach motor encoders to Yukon

dannystaple, 2024-01-09:
Wire the encoders from the motors into the YUkon - pay attention to the wiring as the existing headers on the cables are almost certainly wrong (they were for my old 4Duino setup).

## Definition of ready

- #25

## Definition of done

- [ ] Encoders attached to Yukon
- [ ] Pr merged Motor service adapted to start emitting sensor/encoder left/right updates with timecodes.

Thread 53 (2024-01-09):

Reprint the Yukon plate with 2.5mm holes

dannystaple, 2024-01-09:
The Yukon mounting plate has holes designed for M3 bolts, these should be narrower so M2.5 bolts cut into them. Reprint.
Might be worth adding tall bosses around them, to take the place of the added standoffs for cabling.

## DoD

- [x] FreeCAD updated with narrower items and in git
- [x] Printed item attached with Yukon more firmly held

Closed 2024-04-16.

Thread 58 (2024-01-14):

Chassis plate bolt holes are off in FreeCAD

dannystaple, 2024-01-14:
The bolt cutouts for the Yukon plate do not match up. These are derived from the chassis plate file, which should be updated.

## Definition of Ready

- #26

## Definition of done

- [ ] PR merged with FreeCAD for chassis plate holes verified and correct

dannystaple, 2024-02-18:
Emma and I have started work on this.

Closed 2024-03-16.

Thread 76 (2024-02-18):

Tread Friction On Slope

dannystaple, 2024-02-18:
Testing says it doesn't handle over 10˚ with foam board

Closed 2024-06-21.

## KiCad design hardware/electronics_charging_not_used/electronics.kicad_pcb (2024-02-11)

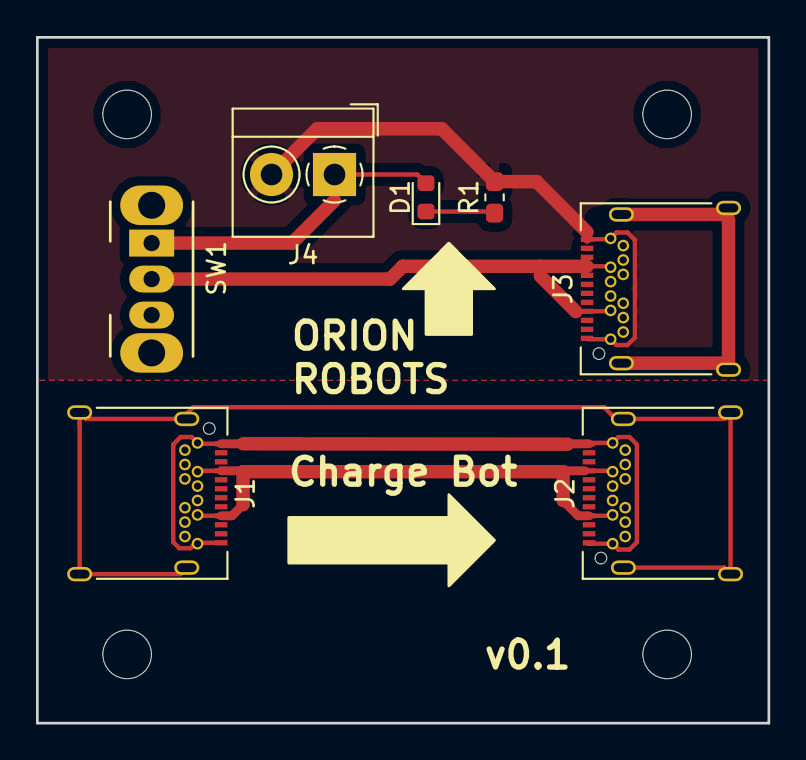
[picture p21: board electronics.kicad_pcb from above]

Board: 2 copper layers, 40.6 x 38.1 mm, 7 parts (0 on the bottom side), 7 nets.

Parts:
D1: LED_Small; LED_0603_1608Metric
J1, J2, J3: USB_C_Receptacle_USB2.0; USB_C_Receptacle_Amphenol_12401548E4-2A
J4: Screw_Terminal_01x02; TerminalBlock_4Ucon_1x02_P3.50mm_Horizontal
R1: 330R; R_0603_1608Metric_Pad1.05x0.95mm_HandSolder
SW1: SW_SPDT; SW_CuK_OS102011MA1QN1_SPDT_Angled

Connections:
unnamed: D1.1, R1.1
unnamed: D1.2, J4.1, SW1.1
unnamed: J1.A1, J1.A12, J1.B1, J1.B12, J2.A1, J2.A12, J2.B1, J2.B12
unnamed: J1.A4, J1.A9, J1.B4, J1.B9, J2.A4, J2.A9, J2.B4, J2.B9
unnamed: J1.S1, J2.S1
unnamed: J3.A1, J3.A12, J3.B1, J3.B12, J4.2, R1.2
unnamed: J3.A4, J3.A9, J3.B4, J3.B9, SW1.2

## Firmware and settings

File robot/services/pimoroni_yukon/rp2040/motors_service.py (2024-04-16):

import sys
import json
import time

import uasyncio as asyncio
from line_following import LineFollower

from pimoroni_yukon import Yukon, SLOT1, SLOT2, SLOT3, SLOT4, SLOT5, SLOT6
from pimoroni_yukon.modules import BigMotorModule, DualMotorModule
from pimoroni_yukon.modules import QuadServoRegModule as QuadServoModule
from pimoroni import REVERSED_DIR

GEAR_RATIO = 30                         # The gear ratio of the motor
ENCODER_CPR = 12                        # The number of counts a single encoder shaft revolution will produce
MOTOR_CPR = GEAR_RATIO * ENCODER_CPR    # The number of counts a single motor shaft revolution will produce

def mqtt_output(topic, message):
    print(f"mqtt_output##{topic}:{message}")

class YukonManager:
    last_contact = 0
    left_motor = None
    right_motor = None
    ready = False
    line_follower_enabled = False

    async def run(self):
        # Setup the yukon
        print("Setting up Yukon")
        yukon = Yukon()
        self.yukon = yukon
        print("Setting up modules")
        left_motor_module  = BigMotorModule(encoder_pio=0,    # Create a BigMotorModule object, with details of the encoder
                                    encoder_sm=0,
                                    counts_per_rev=MOTOR_CPR)
        right_motor_module = BigMotorModule(encoder_pio=0,    # Create a BigMotorModule object, with details of the encoder
                                    encoder_sm=1,
                                    counts_per_rev=MOTOR_CPR)
        self.servo_module = QuadServoModule()
        self.dual_motor_module = DualMotorModule()
        try:
            print("Registering modules")
            yukon.register_with_slot(right_motor_module, SLOT5)
            yukon.register_with_slot(left_motor_module, SLOT2)
            yukon.register_with_slot(self.servo_module, SLOT4)
            yukon.register_with_slot(self.dual_motor_module, SLOT3)
            print("Verifying and initialising")
            yukon.verify_and_initialise(allow_discrepencies=True)
            yukon.enable_main_output()
            line_follower = LineFollower(i2c=yukon.i2c)
            # Enable the modules
            left_motor_module.enable()
            right_motor_module.enable()
            self.servo_module.enable()
            self.dual_motor_module.enable()
            print("Getting motors")
            self.left_motor = left_motor_module.motor
            self.right_motor = right_motor_module.motor
            self.left_motor.direction(REVERSED_DIR)
            self.right_motor.direction(REVERSED_DIR)
            print("Starting main motor loop")
            self.ready = True
            # Service the stream
            while True:
                await asyncio.sleep(0.1)
                yukon.monitor_once()
                if yukon.is_pressed('A'):
                    mqtt_output("yukon/button_a", "pressed")
                if yukon.is_pressed('B'):
                    mqtt_output("yukon/button_b", "pressed")
                if self.line_follower_enabled:
                    differences = line_follower.get_differences()
                    mqtt_output("line_follower/differences", json.dumps(differences))
                if time.ticks_diff(time.ticks_ms(), self.last_contact) % 1000 == 0:
                    readings = yukon.get_readings()
                    print(readings)
                    if self.last_contact != 0:
                        self.last_contact = 0
                        print("No contact from mqtt, stopping")
                        self.stop_wheels()
        finally:
            # Put the board back into a safe state, regardless of how the program may have ended
            yukon.reset()

    async def move_servo(self, index :int, position: float, seconds :float =1, steps: int=100):
        time_per_step = seconds / steps
        servo = self.servo_module.servos[index]
        servo.enable()
        initial_value = servo.value()
        step_size = (position - initial_value) / steps
        for step in range(steps):
            servo.value(initial_value + step_size * step)
            await asyncio.sleep(time_per_step)
        servo.value(position)

    def set_servo(self, position: float, index: int):
        self.servo_module.servos[index].value(position)

    def disable_servo(self, index: int=None):
        if index is not None:
            self.servo_module.servos[index].disable()
        else:
            for servo in self.servo_module.servos:
                servo.disable()

    def set_dual_motor(self, speed: float, index: int):
        if index >= len(self.dual_motor_module.motors):
            raise ValueError(f"Invalid motor index {index}")
        if speed < -1 or speed > 1:
            raise ValueError(f"Invalid speed value {speed}")
        self.dual_motor_module.motors[index].speed(speed)
        self.dual_motor_module.motors[index].enable()

    def stop_dual_motor(self, index: int):
        if index >= len(self.dual_motor_module.motors):
            raise ValueError(f"Invalid motor index {index}")
        self.dual_motor_module.motors[index].stop()

    def set_led_a(self, state: bool):
        self.yukon.set_led('A', state)

    def set_led_b(self, state: bool):
        self.yukon.set_led('B', state)

    def turn_left(self, speed):
        self.left_motor.enable()
        self.left_motor.speed(-speed)
        self.right_motor.enable()
        self.right_motor.speed(speed)
        self.last_contact = time.ticks_ms()

    def turn_right(self, speed):
        self.right_motor.enable()
        self.right_motor.speed(-speed)
        self.left_motor.enable()
        self.left_motor.speed(speed)
        self.last_contact = time.ticks_ms()

    def forward(self, speed, curve):
        print("Driving forward")
        self.left_motor.enable()
        self.right_motor.enable()
        self.left_motor.speed(speed - curve)
        self.right_motor.speed(speed + curve)
        self.last_contact = time.ticks_ms()

    def backward(self, speed, curve):
        self.left_motor.enable()
        self.right_motor.enable()
        self.left_motor.speed(speed - curve)
        self.right_motor.speed(speed + curve)
        self.last_contact = time.ticks_ms()

    def set_values(self, left, right):
        self.left_motor.enable()
        self.right_motor.enable()
        self.left_motor.speed(left)
        self.right_motor.speed(right)
        self.last_contact = time.ticks_ms()

    def stop_wheels(self):
        self.left_motor.stop()
        self.right_motor.stop()

    def all_stop(self):
        self.left_motor.stop()
        self.right_motor.stop()
        self.disable_servo()
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

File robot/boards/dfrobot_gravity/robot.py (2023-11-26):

import DFRobot_RaspberryPi_Expansion_Board
import gpiozero


class Motor(gpiozero.Device):
    def __init__(self, board :DFRobot_RaspberryPi_Expansion_Board.DFRobot_Expansion_Board_IIC, 
                 pwm_chan: int, phase: int):
        self.board = board
        self.pwm_chan = pwm_chan
        self.phase = gpiozero.DigitalOutputDevice(phase)
        self._throttle = 0
        
    def forward(self, speed: float=1):
        self.value = speed

    def backward(self, speed: float=1):
        self.value = -speed

    def reverse(self):
        self.value *= -1

    def stop(self):
        self.value = 0

    @property
    def value(self) -> float:
        return self._throttle

    @value.setter
    def value(self, value: float):
        self._throttle = value
        if value > 0:
            self.phase.off()
            self.board.set_pwm_duty(self.pwm_chan, value * 100.0)
        elif value < 0:
            self.phase.on()
            self.board.set_pwm_duty(self.pwm_chan, 100 - value * 100.0)
        else:
            self.board.set_pwm_duty(self.pwm_chan, 0)
            self.phase.off()

    @property
    def is_active(self) -> bool:
        return self._throttle != 0


class Robot:
    def __init__(self) -> None:
        self.board = DFRobot_RaspberryPi_Expansion_Board.DFRobot_Expansion_Board_IIC(1, 0x10)
        self.board.begin()
        self.board.set_pwm_enable()
        self.board.set_pwm_frequency(1000)
        self.left_motor = Motor(self.board, 0, 0)
        self.right_motor = Motor(self.board, 1, 1)
    
    def forward(self, speed=1, curve_left=0, curve_right=0):
        self.left_motor.forward(speed - curve_left)
        self.right_motor.forward(speed - curve_right)

    def backward(self, speed=1, curve_left=0, curve_right=0):
        self.left_motor.backward(speed + curve_left)
        self.right_motor.backward(speed + curve_right)

    def left(self, speed=1):
        self.left_motor.backward(speed)
        self.right_motor.forward(speed)
    
    def right(self, speed=1):
        self.left_motor.forward(speed)
        self.right_motor.backward(speed)
    
    def reverse(self):
        self.left_motor.value *= -1
        self.right_motor.value *= -1
    
    def stop(self):
        self.left_motor.stop()
        self.right_motor.stop()

    @property
    def value(self):
        return (self.left_motor.value, self.right_motor.value)
    
    @value.setter
    def value(self, values:tuple):
        self.left_motor.value = values[0]
        self.right_motor.value = values[1]

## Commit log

2023-10-01 Add Raspberry Pi preparation
2023-10-08 crickit board motor control
2023-10-15 There's only 1 available i2c bus. The other's hidden.
2023-10-15 Organise motor drivers out to collections
2023-10-18 Whoops- didn't quite match the spec
    [robot.py]
2023-10-21 Get the motor sides correct. Speed up a bit
    [robot.py]
2023-10-22 Test 1 motor at a time first
2023-12-17 We neither need to print or store mqtt creds here
2023-12-31 Fix backward and parameter format
    [service.py]
2024-01-21 Service debugging: - don't need time - all async - Ensure we use the LIneReader super. - Ensure we are specific about the name client in the SerialToMqtt handler. - Add a more distinct marker for mqt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
2024-01-21 Get rid of the print here
2024-01-21 Yukon bugfixes: - Fix up logging messages - There's no monotonic - use time ticks. - We can't get motors until the modules are registered (maybe enabled) - JSon payload message errors should be logge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
2024-01-21 Motors running
2024-01-21 Stop wasn't working correctly
    [motors_service.py]
2024-02-11 Add the all stop handling. Better error handling.
    [motors_service.py]
2024-02-11 Start with electronics files, and images
    [4duino connections.fzz, big_ole_yellow_kicad.kicad_pcb, big_ole_yellow_kicad.kicad_sch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]
2024-02-11 CAD designs imported - not particularly organised, but here.
    [3d_printable_servo_piston.FCStd, 4DuinoPlate.step, Anker_usb_battery v1.step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]
2024-02-11 Tidy up electronics
    [electronics.kicad_pcb, electronics.kicad_sch, electronics.sch]
2024-03-03 CAD with fixed holes and mounting plate
    [BigOleYellow.FCStd, attachment_mounting_plate.FCStd]
2024-03-09 Export Raspberry Pi Part
    [RaspberryPi3a+.FCStd]
2024-03-09 Export a Yukon board part
    [YukonBoard.FCStd]
2024-03-09 Half baked - removing
    [chassis-plate.FCStd]
2024-03-11 Stl shouldn't be here
    [BigOleYellow-Yukon PlateBody.stl]
2024-03-11 Redrawn chassis plate
    [BigOleYellowChassisPlate.FCStd]
2024-03-16 Chassis CAD model less broken. PI and Yukon centered on robot
    [BigOleYellow.FCStd, BigOleYellowChassisPlate.FCStd, RaspberryPi3a+.FCStd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]
2024-03-16 New motor layout
2024-03-24 CAD with more complete hull
    [BigOleYellow.FCStd, YukonBoard.FCStd, attachment_mounting_plate.FCStd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]
2024-03-26 Ok - cut my losses. No ble this way.
2024-04-07 Cad for updated hull
    [BigOleYellow.FCStd]
2024-04-07 Bugfixes and turret basics
    [motors_service.py, service.py]
2024-04-07 LED's, buttons and coping with serial ports.
2024-04-07 LEDs and buttons connected to MQTT bus.
2024-04-07 Servo motor control working
2024-04-07 Added servo joystick
2024-04-14 Full nerf and grabber hardware
    [BigOleYellow.FCStd, GrabAndLift.FCStd, Grabber.FCStd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]
2024-04-15 Rearhull design
    [rearhull2.FCStd]
2024-04-15 Ignore stl's as generated.
2024-04-16 Camera has a picture
2024-04-16 Camera looks good
